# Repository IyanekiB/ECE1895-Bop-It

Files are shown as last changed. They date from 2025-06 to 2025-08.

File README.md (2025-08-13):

# ECE1895 Bop It - Cyberpunk Katana Reaction Game

A handheld, cyberpunk-inspired reaction game built into a custom 3D-printed katana for ECE 1895. This embedded systems project combines real-time sensor processing, dynamic audio-visual feedback, and precision mechanical design into an engaging handheld gaming device.

## Overview

The Cyberpunk Katana houses a complete embedded gaming system within its hilt and blade. Players navigate an OLED menu to select difficulty modes, then respond to three distinct voiced commands within progressively shrinking time windows. The blade illuminates with custom NeoPixel animations while an accelerometer detects precise sword movements.

## Features

### Game Mechanics
- **Four Difficulty Modes**: Easy, Medium, Hard, and Quick mode with separate high score tracking
- **Three Unique Actions**:
  - **Swing It!** - Detected via MPU6050 accelerometer in blade tip (3g threshold)
  - **Sheath It!** - Spring-return switch activation in hilt
  - **Power Boost!** - Rotary encoder interaction in grip
- **Dynamic Difficulty Scaling**: Timer interval reduces with each point scored
- **Progressive Visual Feedback**: Blade color advances every 10 points through custom gradient effects
- **Persistent High Scores**: EEPROM storage with separate tracking for Quick Mode and standard modes

### Hardware Integration
- **Audio System**: Voiced command prompts via Adafruit FX Soundboard and micro-speaker
- **Visual Effects**: 30-60 NeoPixel LED strip embedded in blade with custom animations
- **User Interface**: 128x64 OLED display for menu navigation and game status
- **Power Management**: 18650 Li-Ion battery with TP4056 charging circuit and 3.3V regulation
- **Robust Enclosure**: Custom 3D-printed katana with internal wire routing and snap-in components

## Technical Specifications

### Core Hardware
- **Microcontroller**: ATmega328P (3.3V, Arduino UNO bootloader compatible)
- **Power System**: 18650 Li-Ion battery, TP4056 charger module, 3.3V LDO regulator, slide switch
- **Display**: SSD1306 128x64 OLED (I2C)
- **Audio**: Adafruit FX Soundboard with micro-speaker (active-low triggers)
- **Motion Sensing**: MPU6050 6-DOF IMU (I2C)
- **LED System**: Adafruit NeoPixel strip (30-60 pixels, <500mA total current)
- **User Controls**: Rotary encoder with push button, spring-return sheath switch, menu navigation buttons

### Software Architecture
- **Platform**: AVR-GCC via Arduino IDE
- **Key Libraries**: 
  - `Adafruit_NeoPixel` - LED blade control
  - `Adafruit_SSD1306` - OLED display driver
  - `MPU6050` - Accelerometer interface (I2C)
  - `EEPROM` - Persistent score storage
- **Memory Optimization**: 
  - Flash usage: 98% → 72% optimized
  - SRAM usage: 72% → 23% optimized
  - String literals stored in Flash using `F()` macro

### Mechanical Design
- **Enclosure**: Multi-part 3D-printed katana (handle, blade, mounting brackets)
- **Internal Routing**: Dedicated wire channels and component mounting points
- **Serviceability**: Snap-in OLED window, removable battery access panel
- **Durability**: Vibration-resistant design with robust component mounting

## Team Members

- **Nicholas Cessna** - Enclosure Design & 3D Modeling
- **Nurfadil Rafiuddin** - Hardware Design & System Integration  
- **Vish Thirukallam** - Schematic Design & PCB Layout
- **Iyan Nekib** - Software Architecture & Firmware Development

## Getting Started

### Prerequisites
- Arduino IDE with ATmega328P support
- 3D printer capable of printing PLA/PETG parts
- Basic soldering equipment
- Micro-usb for audio files

### Hardware Assembly

1. **Print Enclosure Components**
   - Use files in `Enclosure_Design_Files/` directory
   - Test-fit display, buttons, encoder, and blade strip before final assembly

2. **PCB Assembly**
   - Follow schematic in `Altium_Files/` directory
   - Install PCB and mainboard in hilt according to wiring diagram
   - Connect OLED, FX Soundboard, NeoPixels, switches, and battery per pin mapping

3. **Software Installation**
   - Flash the latest `Iterations/iteration_6_katana_it/iteration_6_katana_it.ino` file to ATmega328P (Arduino UNO bootloader recommended)
   - Copy provided audio files to FX Soundboard micro-usb

### Operation

1. **Power On**: Use slide switch to activate system
2. **Mode Selection**: Navigate OLED menu to choose difficulty (Easy/Medium/Hard/Quick)
3. **Gameplay**: 
   - Press Start button to begin
   - Respond to audio prompts within time limit
   - Score points for correct responses
   - Reach 99 points for victory celebration
4. **High Scores**: Automatically saved to EEPROM with separate Quick Mode tracking
5. **Power Off**: Use slide switch when finished

## Game Flow

```
System Initialization
    ↓
OLED Menu (Mode Selection)
    ↓
Wait for Start Button
    ↓
Game Loop:
  → Random Command (Audio + OLED)
  → Start Timer
  → Detect Input (IMU/Button/Switch/Encoder)
  → Validate Response
  → LED Feedback (Success/Failure)
  → Update Score & Difficulty
  → Check Win/Loss Conditions
    ↓
Game Over Screen with High Scores
```

## Technical Achievements

### Performance Optimization
- Accelerometer calibration through "Goldilocks trials" for optimal sensitivity
- Memory-constrained optimization for ATmega328P platform
- Real-time sensor fusion and response validation
- Power-efficient design with <500mA current limiting

### System Integration
- Multi-subsystem coordination (audio, visual, sensor, control)
- Mechanical packaging with electronic integration
- Modular design allowing component replacement and maintenance
- Power management and charging system

## Repository Structure

```
ECE1895-Bop-It/
├── README.md                         # This file
├── Altium_Files/                     # PCB design and schematics
│   ├── Button_Breakout_GERBER.zip    # Contains GERBER and NC Drill files
│   └── ....                          # Rest of the PCB layout and Schematics
├── Components/                       # Contains incremental code for the components used
│   ├── Encoder_RGB                   # Code for encoder switches colors (Uses a color matrix based on encoder ticks)
│   ├── Inputs                        # Code for all three inputs used (segregated within the folder)
│   ├── OLED                          # Code(s) for how the OLED is to react during the game
│   ├── OLED_Accel                    # Code that tests out the Accelerometer and the OLED together
│   └── counter_test                  # Code to check whether the counter for each successive input is stored correctly
├── Enclosure_Design_Files/           # 3D printable parts
│   ├── Blade.stl                     # Blade model
│   ├── Blade_Rail.stl                # LED strip housing (goes within blade)
│   ├── Coupler.stl                   # For making the blade and handle sit
│   ├── Handle.stl                    # Handle model
│   ├── Handle_Cover.stl              # Handle Cover model
│   └── Sheath.stl                    # The Sheath-It Cover that goes on the Handle
├── Iterations/                       # Iterations of each instance of the Bop-It project
│   ├── iteration_1_katana_it         # Contains the prelimanary Iteration w/ basic functionality
│   ├── iteration_2_katana_it         # Contains more in-depth regarding the inputs
│   ├── iteration_3_katana_it         # Ran into memeory issues so restructured code to better fit with memory usage
│   ├── iteration_4_katana_it         # Contains stable code which runs with audio sound board
│   ├── iteration_5_katana_it         # Comtains code that was tweaked to fit a different LED strip
│   └── iteration_6_katana_it         # Most stable version of the project (Currently used)
├── LED_Animations/                   # Conceptual animations for Input/Success/Game Over
│   ├── 30LED_Rainbow                 # Animation for Boost-It!
│   ├── 30LED_Success                 # Animation for every correct input
│   └── 60LED_Success                 # Animation for every correct input (60 LED)
├── sensor_examples/                  # Code examples for limiting memory usage (If needed)
│   ├── SDFatExample.ino              # Reduces the usage of the SD Card by 20%
│   └── accel.cpp                     # Contains code for receiving Accelerometer data
└── Pseudocode for Bop-It.txt         # Inital Pseudocode for the project
```

## Acknowledgments

Special thanks to the ECE 1895 course staff and the University of Pittsburgh Electrical and Computer Engineering Department for project guidance and laboratory resources.

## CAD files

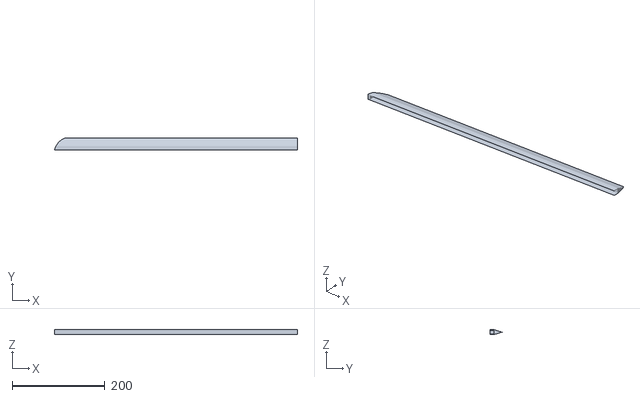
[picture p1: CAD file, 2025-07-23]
Enclosure_Design_Files/Blade.stl
523.8 x 26.0 x 10.00

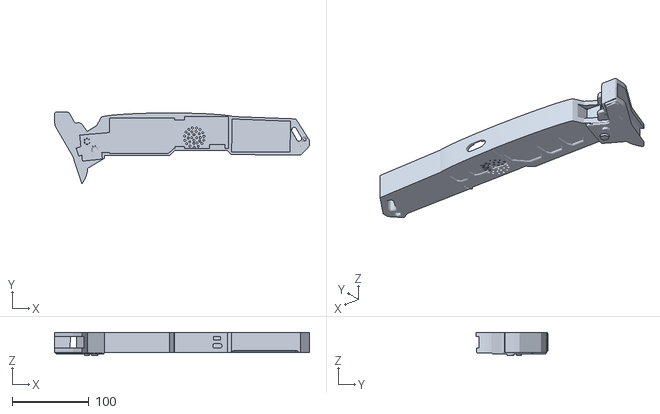
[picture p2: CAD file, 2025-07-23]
Enclosure_Design_Files/Handle.stl
331.5 x 93.0 x 30.1

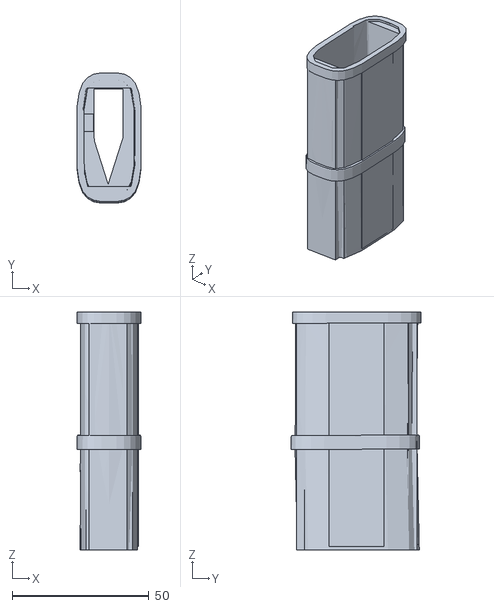
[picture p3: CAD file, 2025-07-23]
Enclosure_Design_Files/Sheath.stl
23.3 x 47.6 x 86.9

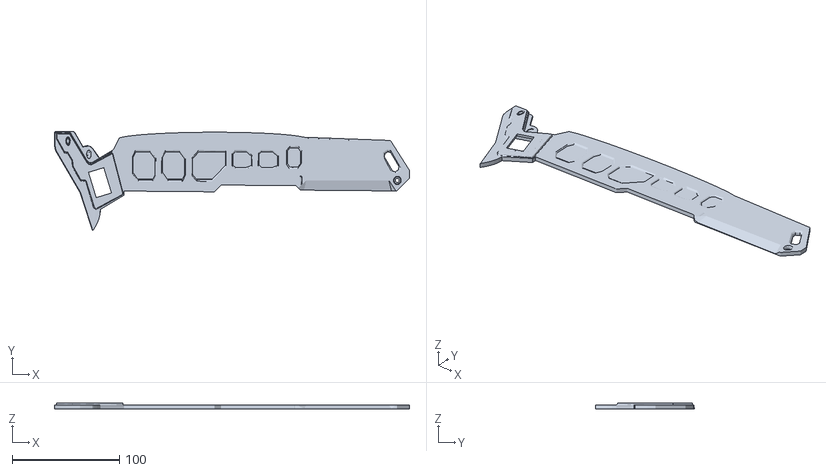
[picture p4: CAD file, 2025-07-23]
Enclosure_Design_Files/Handle_Cover.stl
331.1 x 92.8 x 5.60

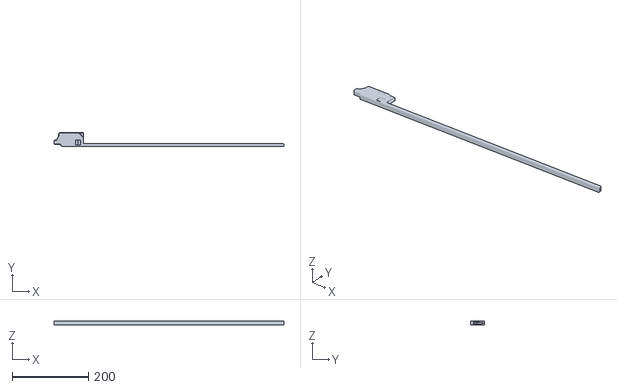
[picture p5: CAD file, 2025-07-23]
Enclosure_Design_Files/Blade_Rail.stl
602.9 x 36.4 x 10.0

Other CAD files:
Enclosure_Design_Files/Coupler.stl

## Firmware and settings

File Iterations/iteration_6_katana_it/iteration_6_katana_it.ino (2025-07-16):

#include <Wire.h>
#include <Adafruit_GFX.h>
#include <Adafruit_SSD1306.h>
#include <EEPROM.h>
#include <Adafruit_NeoPixel.h>
#include <MPU6050.h>

// Pinout
#define OLED_WIDTH       128
#define OLED_HEIGHT      64
#define OLED_RESET       -1

#define SWITCH_PIN        2
#define MODE_BTN_PIN      3
#define SHEATH_PIN        6

#define NEOPIXEL_PIN      7
#define NUM_LEDS         30   // Change this as well after debugging

#define ENC_A             5   // Terminal A (right-most pin when encoder is facing you)
#define ENC_B             8   // Terminal B (left-most pin when encoder is facing you)

#define FX_BOOST_PIN      9   // T0 - Boost It
#define FX_SHEATH_PIN     10  // T1 - Sheath It
#define FX_SWING_PIN      11  // T2 - Swing It
#define FX_GAME_ON        12  // T3 - Game On
#define FX_GAME_OVER      13  // T4 - Game Over

Adafruit_NeoPixel strip(NUM_LEDS, NEOPIXEL_PIN, NEO_GRBW + NEO_KHZ800); // Remember to change this depending on what strip we end up using
Adafruit_SSD1306 display(OLED_WIDTH, OLED_HEIGHT, &Wire, OLED_RESET);
MPU6050 mpu;

#define SWING_MAG_THRESHOLD 3  // G's

long encPosition = 0;
int lastEncCLK = LOW;

const int EEPROM_ADDR_HIGH = 0;
int highScore = 0;
bool oledOn = false;
uint8_t modeCount = 1;
int lastModeState = HIGH;
uint16_t boostHue = 0;

float lastX = 0, lastY = 0, lastZ = 0;
int16_t ax, ay, az;

// Adafruit FX Soundboard Trigger Helper (ACTIVE LOW)
void playSound(uint8_t fxPin) {
  pinMode(fxPin, OUTPUT);     
  digitalWrite(fxPin, HIGH);   // Ensure idle
  delay(20);
  digitalWrite(fxPin, LOW);    // Pulse LOW
  delay(250);                  // Hold LOW at least 200-300ms
  digitalWrite(fxPin, HIGH);   // Return HIGH
  delay(100);                  // Wait before next trigger
}


// NeoPixel helpers
void stripOff() {
  for (uint8_t i = 0; i < NUM_LEDS; i++)
    strip.setPixelColor(i, 0,0,0,0);
  strip.show();
}
void flashRed(uint16_t ms = 350) {
  for (uint8_t i = 0; i < NUM_LEDS; i++)
    strip.setPixelColor(i, 255,0,0,0);
  strip.show();
  delay(ms);
  stripOff();
}
void yellowMiddleOut(uint16_t duration_ms = 650) {
  // How many animation steps (pairs of LEDs to light up)
  int steps = NUM_LEDS / 2 + (NUM_LEDS % 2 ? 1 : 0);
  uint16_t frameDelay = duration_ms / steps;

  // Turn off all LEDs first
  stripOff();

  for (int i = 0; i < steps; i++) {
    int midLeft  = (NUM_LEDS - 1) / 2 - i;
    int midRight = NUM_LEDS / 2 + i;
    uint32_t yellow = strip.Color(255, 180, 0, 0); // Bright yellow

    if (midLeft >= 0) strip.setPixelColor(midLeft, yellow);
    if (midRight < NUM_LEDS) strip.setPixelColor(midRight, yellow);

    strip.show();
    delay(frameDelay);
  }
  // brief hold at max brightness
  delay(180);
  stripOff();
}
void blueBladeExtend(uint16_t extend_ms = 480) {
  uint16_t frameDelay = extend_ms / NUM_LEDS;
  uint32_t electricBlue = strip.Color(60, 200, 255, 0);
  stripOff();
  for (int i = 0; i < NUM_LEDS; i++) {
    strip.setPixelColor(i, electricBlue);
    strip.show();
    delay(frameDelay);
  }
}
void blueBladeRetract(uint16_t retract_ms = 420) {
  uint16_t frameDelay = retract_ms / NUM_LEDS;
  for (int i = NUM_LEDS - 1; i >= 0; i--) {
    strip.setPixelColor(i, 0,0,0,0);
    strip.show();
    delay(frameDelay);
  }
}
void showGradientBlade(int count, uint16_t baseHue) {
  count = constrain(count, 0, NUM_LEDS);
  uint16_t delta = 4000;
  for (uint8_t i = 0; i < NUM_LEDS; i++) {
    if (i < count) {
      uint16_t thisHue = baseHue + ((uint32_t)i * delta / (count>1?count-1:1));
      uint32_t color = strip.gamma32(strip.ColorHSV(thisHue));
      uint8_t r = (color >> 16) & 0xFF;
      uint8_t g = (color >> 8) & 0xFF;
      uint8_t b = color & 0xFF;
      strip.setPixelColor(i, r, g, b, 0);
    } else {
      strip.setPixelColor(i, 0,0,0,0);
    }
  }
  strip.show();
}

// Encoder
void updateEncoder() {
  int clk = digitalRead(ENC_A);
  if (clk != lastEncCLK) {
    if (digitalRead(ENC_B) != clk) encPosition++;
    else                           encPosition--;
  }
  lastEncCLK = clk;
}

// Power toggle
bool checkPowerToggle() {
  static int last = HIGH;
  int cur = digitalRead(SWITCH_PIN);
  if (cur != last) {
    delay(40);
    cur = digitalRead(SWITCH_PIN);
    if (cur != last && cur == LOW) {
      last = cur;
      return true;
    }
  }
  last = cur;
  return false;
}

// OLED UI
void showSplash() {
  display.clearDisplay();
  display.setTextSize(2);
  display.setTextColor(WHITE);
  display.setCursor(0,0);
  display.println(F("Katana-It!"));
  display.display();
}
void showMenu(uint8_t highlight) {
  display.clearDisplay();
  display.setTextSize(1);
  display.setCursor(0,0);
  display.println(F("Mode Select:"));
  for (uint8_t i = 1; i <= 4; i++) {
    display.setCursor(0, 18 + (i-1)*12);
    display.print(i == highlight ? F("> ") : F("  "));
    display.print(i);
    display.print(F(") "));
    switch(i) {
      case 1: display.println(F("Easy"));   break;
      case 2: display.println(F("Medium")); break;
      case 3: display.println(F("Hard"));   break;
      case 4: display.println(F("Quick"));  break;
    }
  }
  display.display();
}
void showModeConfirmation(uint8_t mode) {
  display.clearDisplay();
  display.setTextSize(2);
  display.setCursor(0,16);
  switch(mode) {
    case 1: display.println(F("Easy Mode"));   break;
    case 2: display.println(F("Medium Mode")); break;
    case 3: display.println(F("Hard Mode"));   break;
    case 4: display.println(F("Quick Mode"));
            display.setTextSize(1);
            display.setCursor(0,40);
            display.println(F("Start at 90pts"));
            break;
  }
  display.display();
  delay(1300);
  display.clearDisplay(); display.display();
}
void waitForStartButton() {
  display.clearDisplay();
  display.display();
  while (digitalRead(SWITCH_PIN) == HIGH) delay(8);
  while (digitalRead(SWITCH_PIN) == LOW) delay(8);
}
void modeSelectMenu() {
  modeCount = 1;
  showMenu(modeCount);
  lastModeState = digitalRead(MODE_BTN_PIN);
  unsigned long lastPress = millis();
  while (1) {
    if (checkPowerToggle()) { oledOn = false; powerDownOLED(); return; }
    int m = digitalRead(MODE_BTN_PIN);
    if (m != lastModeState) {
      delay(25);
      m = digitalRead(MODE_BTN_PIN);
      if (m == LOW) {
        modeCount = (modeCount % 4) + 1;
        showMenu(modeCount);
        lastPress = millis();
      }
    }
    lastModeState = m;
    if (millis() - lastPress > 5000) break;
    delay(10);
  }
  showModeConfirmation(modeCount);
  runGame();
}

// Setup & Loop
void setup() {
  delay(500);

  Wire.begin();
  display.begin(SSD1306_SWITCHCAPVCC, 0x3C);
  display.clearDisplay(); display.display();

  delay(500); // Allow time for OLED to initialize

  mpu.initialize();
  EEPROM.get(EEPROM_ADDR_HIGH, highScore);

  delay(500);

  pinMode(SWITCH_PIN, INPUT_PULLUP);
  pinMode(MODE_BTN_PIN, INPUT_PULLUP);
  pinMode(SHEATH_PIN, INPUT_PULLUP);
  pinMode(ENC_A, INPUT);
  pinMode(ENC_B, INPUT);
  lastEncCLK = digitalRead(ENC_A);

  delay(500);

  strip.begin();
  strip.setBrightness(80);
  stripOff();

  delay(500);

  // Set all FX trigger pins to OUTPUT and HIGH (idle for ACTIVE LOW)
  pinMode(FX_BOOST_PIN, OUTPUT);   digitalWrite(FX_BOOST_PIN, HIGH);
  pinMode(FX_SHEATH_PIN, OUTPUT);  digitalWrite(FX_SHEATH_PIN, HIGH);
  pinMode(FX_SWING_PIN, OUTPUT);   digitalWrite(FX_SWING_PIN, HIGH);
  pinMode(FX_GAME_ON, OUTPUT);     digitalWrite(FX_GAME_ON, HIGH);
  pinMode(FX_GAME_OVER, OUTPUT);   digitalWrite(FX_GAME_OVER, HIGH);

  randomSeed(analogRead(A5));
}

void loop() {
  waitForStartButton();

  delay(100);

  playSound(FX_GAME_ON); // Play "Game On" sound (T3, active LOW)

  showSplash();
  unsigned long splashStart = millis();
  while (millis() - splashStart < 1600) {
    if (checkPowerToggle()) { oledOn = false; powerDownOLED(); return; }
    delay(8);
  }
  display.clearDisplay(); display.display();

  oledOn = true;

  while (oledOn) {
    if (checkPowerToggle()) { oledOn = false; powerDownOLED(); return; }
    if (digitalRead(MODE_BTN_PIN) == LOW) {
      while (digitalRead(MODE_BTN_PIN) == LOW) delay(8);
      modeSelectMenu();
      break;
    }
    delay(8);
  }
}

// IMU and Game Logic
bool isSwingDetected() {
  mpu.getAcceleration(&ax, &ay, &az);

  float gx = ax / 16384.0;
  float gy = ay / 16384.0;
  float gz = az / 16384.0;

  float mag = sqrt(gx*gx + gy*gy + gz*gz);

  Serial.print("Accel Mag: "); Serial.println(mag); // For tuning

  // At rest, mag ~1.0; swinging sharply gives higher values
  return (mag > SWING_MAG_THRESHOLD);
}

void runGame() {
  unsigned long baseInterval;
  int score = 0;

  switch(modeCount) {
    case 1: baseInterval = 4700; score = 0;  break;
    case 2: baseInterval = 3800; score = 0;  break;
    case 3: baseInterval = 2800; score = 0;  break;
    case 4: baseInterval = 4700; score = 90; break;
  }
  // unsigned long baseInterval = (modeCount==1 ? 4700 : modeCount==2 ? 3800 : 2800);
  unsigned long interval = baseInterval;
  const unsigned long minInterval = 600; // ms

  unsigned long lastCueTime = millis();
  // int score = 0;

  display.clearDisplay();
  display.setTextSize(1);
  display.setCursor(0,0);
  display.print(F("Score: "));
  display.println(score);
  display.display();

  while (oledOn) {
    updateEncoder();
    if (checkPowerToggle()) { powerDownOLED(); return; }

    if (millis() - lastCueTime >= interval) {
      lastCueTime = millis();
      uint8_t cmd = random(1,4); // 1=Swing, 2=Sheath, 3=Boost
      const char* txt = (cmd==1 ? "Swing It!" : cmd==2 ? "Sheath It!" : "Boost It!");

      display.clearDisplay();
      display.setTextSize(1);
      display.setCursor(0,0);
      display.print(F("Score: "));
      display.println(score);
      display.setTextSize(2);
      display.setCursor(0,16);
      display.println(txt);
      display.display();

      stripOff();
      // ---- Trigger the correct sound immediately (active LOW pulse) ----
      if (cmd == 1) playSound(FX_SWING_PIN);
      else if (cmd == 2) playSound(FX_SHEATH_PIN);
      else if (cmd == 3) playSound(FX_BOOST_PIN);

      long baseEnc = encPosition;
      long maxDelta = 0;
      bool correct = false;
      bool lastSheathState = (digitalRead(SHEATH_PIN) == LOW);
      bool lastSwingState = false;
      unsigned long start = millis();

      if (cmd == 3) { // BOOST IT
        boostHue = random(0, 65536);
        long prevLit = 0;
        bool encoderMoved = false;
        while (millis() - start < interval) {
          updateEncoder();
          if (checkPowerToggle()) { powerDownOLED(); return; }
          long curEnc = encPosition;                  // Current encoder position
          int delta = abs(curEnc - baseEnc);          // How far the encoder has moved since cue
          if (delta > maxDelta) maxDelta = delta;     // Track maximum distance for this round
          int num_lit = (maxDelta / 2) * 2;
          num_lit = constrain(num_lit, 0, NUM_LEDS);  // For every 2 encoder ticks, light up 2 LEDs and clamp to LED strip length
          if (num_lit != prevLit) {
            showGradientBlade(num_lit, boostHue);
            prevLit = num_lit;
          }
          if (num_lit > 0) encoderMoved = true;

          if (digitalRead(SHEATH_PIN) == LOW) {
            flashRed(); playSound(FX_GAME_OVER); showGameOver(score); return;
          }
          if (isSwingDetected()) {
            flashRed(); playSound(FX_GAME_OVER); showGameOver(score); return;
          }
          delay(12);
        }
        if (!encoderMoved) { flashRed(); playSound(FX_GAME_OVER); showGameOver(score); return; }
        else correct = true;
        stripOff();
      }
      else if (cmd == 1) { // Swing
        long swingBaseEnc = encPosition;
        bool curSwing, lastSwingState = false;
        while (millis() - start < interval) {
          updateEncoder();
          if (checkPowerToggle()) { powerDownOLED(); return; }
          int encDelta = abs(encPosition - swingBaseEnc);
          if (encDelta >= 2) {
            flashRed(); playSound(FX_GAME_OVER); showGameOver(score); return;
          }
          curSwing = isSwingDetected();
          if (!lastSwingState && curSwing) {
            yellowMiddleOut();
            correct = true; break;
          }
          lastSwingState = curSwing;
          if (digitalRead(SHEATH_PIN) == LOW) {
            flashRed(); playSound(FX_GAME_OVER); showGameOver(score); return;
          }
          delay(12);
        }
      }
      else if (cmd == 2) { // Sheath
        blueBladeExtend();
        long sheathBaseEnc = encPosition;
        bool curSheath, lastSheathState = (digitalRead(SHEATH_PIN) == LOW);
        while (millis() - start < interval) {
          updateEncoder();
          if (checkPowerToggle()) { powerDownOLED(); return; }
          int encDelta = abs(encPosition - sheathBaseEnc);
          if (encDelta >= 2) {
            flashRed(); playSound(FX_GAME_OVER); showGameOver(score); return;
          }
          curSheath = (digitalRead(SHEATH_PIN) == LOW);
          if (!lastSheathState && curSheath) {
            blueBladeRetract();
            correct = true; break;
          }
          lastSheathState = curSheath;
          if (isSwingDetected()) {
            flashRed(); playSound(FX_GAME_OVER); showGameOver(score); return;
          }
          delay(12);
        }
      }

      if (!correct) { flashRed(); playSound(FX_GAME_OVER); showGameOver(score); return; }

      score++;
      // Decrease interval for next round, but we shouldn't go below minInterval -- i think
      if (interval > minInterval + 100) interval -= 200;
      else interval = minInterval;

      // Score logic if game reaches 99 points (which really who's gonna get there)
      if(score>=99){
        stripOff();
        playSound(FX_GAME_OVER);
        showGameOver(score);
        return;
      }

      display.clearDisplay();
      display.setTextSize(1);
      display.setCursor(0,0);
      display.print(F("Score: "));
      display.println(score);
      display.display();
      delay(140);
      stripOff();
    }
  }
}

// Game Over, Power Down
void showGameOver(int finalScore) {
  flashRed();
  playSound(FX_GAME_OVER);
  display.clearDisplay();
  display.setTextSize(2);
  display.setCursor(0,0);
  display.println(F("GAME OVER"));
  display.setTextSize(1);
  display.setCursor(0,32);
  display.print(F("Score: "));
  display.println(finalScore);

  if ((modeCount != 4) && (finalScore > highScore)) {
    highScore = finalScore;
    EEPROM.put(EEPROM_ADDR_HIGH, highScore);
  }
  display.setCursor(0,44);
  display.print(F("High Score: "));
  if (modeCount == 4) {
    display.println(finalScore);
  } else {
    display.println(highScore);
  }
  display.display();

  unsigned long t0 = millis();
  while (millis() - t0 < 8000) {
    if (checkPowerToggle()) { oledOn = false; powerDownOLED(); return; }
  }
  oledOn = false;
  powerDownOLED();
}

void powerDownOLED() {
  stripOff();
  display.clearDisplay();
  display.display();
}

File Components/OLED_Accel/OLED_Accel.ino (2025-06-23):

#include <Wire.h>
#include <Adafruit_GFX.h>
#include <Adafruit_SSD1306.h>
#include <Arduino_LSM6DSOX.h>
#include <EEPROM.h>

// OLED & Game pins
#define OLED_WIDTH       128
#define OLED_HEIGHT      64
#define OLED_RESET       -1
#define SWITCH_PIN        2
#define MODE_BTN_PIN      3
#define BUZZER_PIN        5
#define SHEATH_PIN        6

Adafruit_SSD1306 display(OLED_WIDTH, OLED_HEIGHT, &Wire, OLED_RESET);

// Rotary encoder pins
const uint8_t ENC_CLK = 9, ENC_DT = 8;
// RGB LED pins
const uint8_t RED_PIN = 11, BLUE_PIN = 12, GREEN_PIN = 13;
// Color palette
const uint8_t colorTable[][3] = {
  {255,0,0}, {0,0,255}, {0,255,0}, {255,255,0}, {0,255,255}, {255,0,255}, {255,255,255}
};
const uint8_t NUM_COLORS = sizeof(colorTable) / sizeof(colorTable[0]);
// EEPROM & game state
const int EEPROM_ADDR_HIGH = 0;
int highScore = 0;
bool oledOn = false;
uint8_t modeCount = 1;
int lastModeState = HIGH;
long encPosition = 0;
int lastEncCLK = LOW;

// Swing detection state
float lastX = 0, lastY = 0, lastZ = 0;
const float SWING_DELTA_THRESHOLD = 0.2;

// ---- Utility ----
bool checkPowerToggle() {
  static int last = HIGH;
  int cur = digitalRead(SWITCH_PIN);
  if (cur != last) {
    delay(50);
    cur = digitalRead(SWITCH_PIN);
    if (cur != last && cur == LOW) { last = cur; return true; }
  }
  last = cur;
  return false;
}
void updateEncoder() {
  int clk = digitalRead(ENC_CLK);
  if (clk != lastEncCLK) {
    if (digitalRead(ENC_DT) != clk) encPosition++;
    else encPosition--;
  }
  lastEncCLK = clk;
}
void setRGB(uint8_t r, uint8_t g, uint8_t b) {
  digitalWrite(RED_PIN, r > 128 ? HIGH : LOW);
  digitalWrite(GREEN_PIN, g > 128 ? HIGH : LOW);
  digitalWrite(BLUE_PIN, b > 128 ? HIGH : LOW);
}

// ---- Input logic modularized ----
bool checkSheathEdge(bool &lastSheathState) {
  bool curSheath = (digitalRead(SHEATH_PIN) == LOW);
  bool edge = !lastSheathState && curSheath;
  lastSheathState = curSheath;
  return edge;
}
bool checkBoostEdge(long &baseEnc) {
  if (encPosition != baseEnc) { baseEnc = encPosition; return true; }
  return false;
}
bool checkSwingEdge(bool &lastSwingState, bool showDebug = false) {
  float x, y, z;
  bool swung = false;
  if (IMU.accelerationAvailable()) {
    IMU.readAcceleration(x, y, z);
    float dx = abs(x - lastX), dy = abs(y - lastY), dz = abs(z - lastZ);
    swung = (dx > SWING_DELTA_THRESHOLD || dy > SWING_DELTA_THRESHOLD || dz > SWING_DELTA_THRESHOLD);
    lastX = x; lastY = y; lastZ = z;
    if (showDebug) Serial.println(swung ? "Swing: YES" : "Swing: NO");
  }
  bool edge = !lastSwingState && swung;
  lastSwingState = swung;
  return edge;
}

// ---- OLED display helpers ----
void oledClear() {
  display.clearDisplay(); // Always enough, never double with fillScreen(BLACK)
}
void showScorePrompt(int score, const char *prompt, uint8_t textSize=2) {
  oledClear();
  display.setTextSize(1);
  display.setCursor(0,0);
  display.print("Score: ");
  display.println(score);
  display.setTextSize(textSize);
  display.setCursor(0,16);
  display.println(prompt);
  display.display();
}

// ---- Main ----
void setup() {
  Serial.begin(9600);
  Wire.begin();
  if (!display.begin(SSD1306_SWITCHCAPVCC, 0x3C)) { Serial.println(F("OLED init failed")); while (1); }
  display.clearDisplay(); display.display(); delay(100);
  if (!IMU.begin()) { Serial.println("Failed to initialize IMU!"); while (1); }
  EEPROM.get(EEPROM_ADDR_HIGH, highScore);
  pinMode(SWITCH_PIN,INPUT_PULLUP); pinMode(MODE_BTN_PIN,INPUT_PULLUP);
  pinMode(BUZZER_PIN,OUTPUT); pinMode(SHEATH_PIN,INPUT_PULLUP);
  digitalWrite(BUZZER_PIN,LOW);
  pinMode(ENC_CLK,INPUT); pinMode(ENC_DT,INPUT); lastEncCLK = digitalRead(ENC_CLK);
  pinMode(RED_PIN,OUTPUT); pinMode(GREEN_PIN,OUTPUT); pinMode(BLUE_PIN,OUTPUT);
  setRGB(0,0,0);
  randomSeed(analogRead(A5));
  Serial.print("Swing threshold: "); Serial.println(SWING_DELTA_THRESHOLD, 2);
}
void loop() {
  if (checkPowerToggle()) {
    oledOn = !oledOn;
    Serial.println(oledOn ? "OLED ON" : "OLED OFF");
    if (oledOn)      powerUpAndSelectMode();
    else             powerDownOLED();
  }
}

void powerUpAndSelectMode() {
  delay(10);
  oledClear();
  display.setTextSize(2); display.setTextColor(WHITE); display.setCursor(0,0); display.println("Bop-It!");
  display.setTextSize(1); display.setCursor(0,32); display.display();
  unsigned long t0 = millis(); while (millis() - t0 < 2000) if (checkPowerToggle()) { oledOn = false; powerDownOLED(); return; }
  modeCount = 1; showMenu(); lastModeState = digitalRead(MODE_BTN_PIN); unsigned long lastPress = millis();
  while (millis() - lastPress < 3000) {
    if (checkPowerToggle()) { oledOn = false; powerDownOLED(); return; }
    int m = digitalRead(MODE_BTN_PIN);
    if (m != lastModeState) { delay(50); m = digitalRead(MODE_BTN_PIN);
      if (m == LOW) { modeCount = (modeCount % 3) + 1; Serial.print("Mode = "); Serial.println(modeCount); showMenu(); lastPress = millis(); }
    }
    lastModeState = m;
  }
  oledClear(); display.setTextSize(2); display.setCursor(0,16);
  if (modeCount==1) display.println("Easy Mode"); else if (modeCount==2) display.println("Medium Mode"); else display.println("Hard Mode");
  display.display();
  t0 = millis(); while (millis() - t0 < 2000) if (checkPowerToggle()) { oledOn = false; powerDownOLED(); return; }
  runGame();
}
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

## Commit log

2025-06-15 Have the oled display working with buttons as well as mode selection. Will try to include a buzzer to test whether the input cycling works
    [OLED_ON_test.ino, OLED_startup_test.ino]
2025-06-15 Added a buzzer to test it with randomized input selection. Need to add counter and Game Over message along with actual inputs
    [OLED_buzzer_test.ino]
2025-06-16 Added a screen after Game Over to allow user to play again. Fixed issue with OFF switch and now turns off at anytime upon btn click (debounce). Working on inputs now.
    [OLED_counter_replay.ino, counter_test.ino]
2025-06-16 Added an encoder and rgb test code as well as the working for the boost it code
2025-06-16 Fixed major bugs reagrding how Game Over showed up, added high score tracker and buzzer for Game Over. Will add Accelerometer for final test
    [iteration_1_katana_it.ino, sheath_it_test.ino]
2025-06-16 Tried initializing accelerometer but had issues with SPI.
    [swing_it_test.ino]
2025-06-16 Reverted score to 0
    [iteration_1_katana_it.ino]
2025-06-23 Added the most recent working iteration of the Bop-It project; Might have ram issues later
    [30LED_Success.ino, 60LED_Success.ino, iteration_3_katana_it.ino]
2025-06-24 Iteration 4 not working with SD Card; Running into RAM issues
    [iteration_4_katana_it.ino]
2025-06-25 Added latest working iteration 5; Has new boost it feature and fixed start/mode logic
    [iteration_5_katana_it.ino]
2025-06-28 Made updates to Iteration 4 and 5; Iteration 4 is the most latest working version of Katana-It; Still issues with how the sound is not being played for inputs
    [iteration_4_katana_it.ino, iteration_5_katana_it.ino]
2025-06-28 Iteration 4 is the most up-to-date code for the Bop-It; The audio and everything is working as intended; This iteration uses the adafruit fx sound board
2025-06-30 Updated most stable version Iteration 4; Everything seems to be working great; Minor bugs like program hangs but that is rare can be fixed if you click hardware reset
    [iteration_4_katana_it.ino]
2025-06-30 Imported all Altium Files
    - Added Altium .PcbDoc, .SchDoc, and GERBER files for Rotary Encoder Board, Button Breakout Board, and Main Board.
    [Button_Breakout_PCB.PcbDoc, Button_Breakout_sch.SchDoc, MainBoard_PCB.PcbDoc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]
2025-07-07 Iteration 6 is the latest now; Has Quick Mode to showcase 99pt case scenario and remember to change GRB to GRBW and LED count to 60 from 30
2025-07-16 Switched the lsd6do32 with an mpu6050 which is more responsive and works well with the design
2025-07-23 Added the Enclosure Design Files
2025-07-23 Readded the files for the enclosure again
    [Blade.stl, Blade_Rail.stl, Coupler.stl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]
